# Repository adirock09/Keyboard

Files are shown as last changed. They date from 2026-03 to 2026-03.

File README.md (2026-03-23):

# Keyboard
I wanted to make a mecanical keyboard ,So i Choose a 60% layout Keyboard as it is compact and funtional enough. We will be using switch matrix wo we need less gpio pins
## Features

- Base on Raspberry pico
- Has 61 keys ( 60% Keyboard Matrix)

- ## 🧾 Bill of Materials (BOM)

| # | Item | Description | Quantity | Unit Price (USD) | Total (USD) | Link |
|---|---|---|---|---|---|---|
| 1 | 80Retros x HMX Volume | Mechanical switches (pack of 35) | 2 packs | 17.8 | 35.6 | https://stackskb.com/store/hmx-volume-0-pack-of-35/ |
| 2 | 1N4148 Diode | DO-35 switching diode | 61 | 0 | 0 | | Already have
| 3 | Raspberry Pi Pico H | RP2040 microcontroller board | 1 | 5.5 | 5.5 | https://robu.in/product/raspberry-pi-pico-with-headers/ |
| 4 | MAO Keycap Set | Full keycap set | 1 | 44.5 | 44.5 | https://stackskb.com/store/akko-panda-mao-keycap-set-142-key/ |
| 5 | Screw-In Stabilizers V2 | Keyboard stabilizers | 1 set | 17.1 | 17.1 | https://stackskb.com/store/durock-smokey-screw-in-stabilizers-v2/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 |
| 6 | PCB + Shipping | PCB fabrication (JLCPCB) | 1 | 29.51 | 29.51 | https://jlcpcb.com |

### 💰 Total Cost
**$132.21 USD**<br>
I am bidding for **100 USD** and rest **money will be paid by me myself**.

## Hardware
- Raspberry Pico 
- Cherry MX compatible Switches
- Diode
- 2 layer PCB

## Firmware
- It is Based on KMK and Circuit Python

- ### Schematic
Screenshot (171)

- ###  PCB Design
Screenshot (170)

- ### 3D Design
- <br>
Screenshot (284)

<br>
Screenshot (281)

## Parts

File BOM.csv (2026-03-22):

Index | Quantity | Part Number | Manufacturer Part Number | Description | Available | Unit Price | Extended Price USD | Link
1 | 2 (pack of 35) | 1644-MX2A-HC1B-ND | 80Retros x HMX Volume |  | 2 | 17.8 | 35.6 | https://stackskb.com/store/hmx-volume-0-pack-of-35/
2 | 61 | 1N4148FSCT-ND | 1N4148TR | DIODE STANDARD 100V 200MA DO35 | Already have | 0 | 0
3 | 1 | 2648-SC0917-ND | SC0917 | Raspberry Pi Pico H RP2040 | 1 | 5.5 | 5.5 | https://robu.in/product/raspberry-pi-pico-with-headers/
4 | 1 | Keycaps Set |  | MAO Keycap Set |  | 44.5 | 44.5 | https://stackskb.com/store/akko-panda-mao-keycap-set-142-key/
5 | 1 | Stabilizer |  | Screw-In Stabilizers V2 |  | 17.1 | 17.1 | https://stackskb.com/store/durock-smokey-screw-in-stabilizers-v2/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
6 | 1 | PCB + Shipping | JLCPCB | PCB fabrication and shipping |  | 29.51 | 29.51 | https://jlcpcb.com

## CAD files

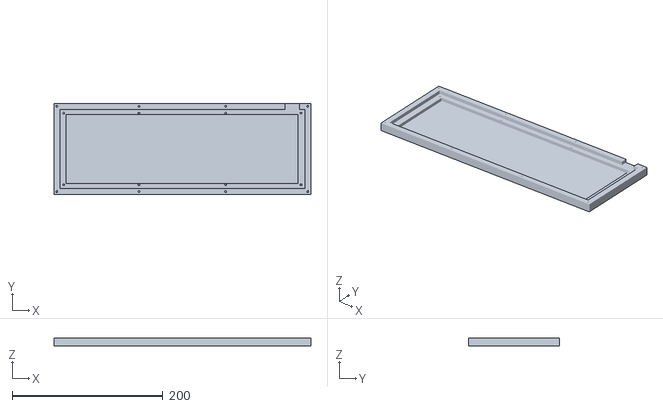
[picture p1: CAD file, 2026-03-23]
KeyBoard/Production/LowCover.stl
341.0 x 121.0 x 11.2

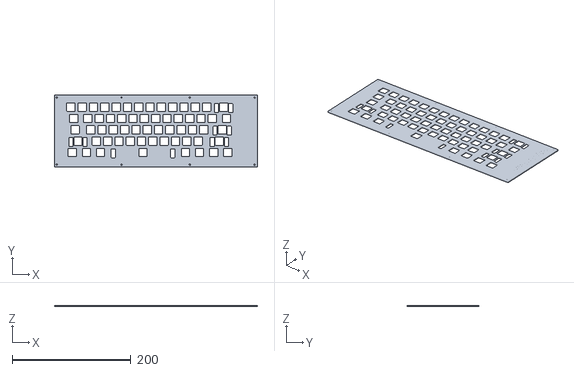
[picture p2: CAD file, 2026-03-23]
KeyBoard/Production/UpCase.stl
341.8 x 121.2 x 2.00

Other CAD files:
KeyBoard/CAD/Keyboard(2).f3d

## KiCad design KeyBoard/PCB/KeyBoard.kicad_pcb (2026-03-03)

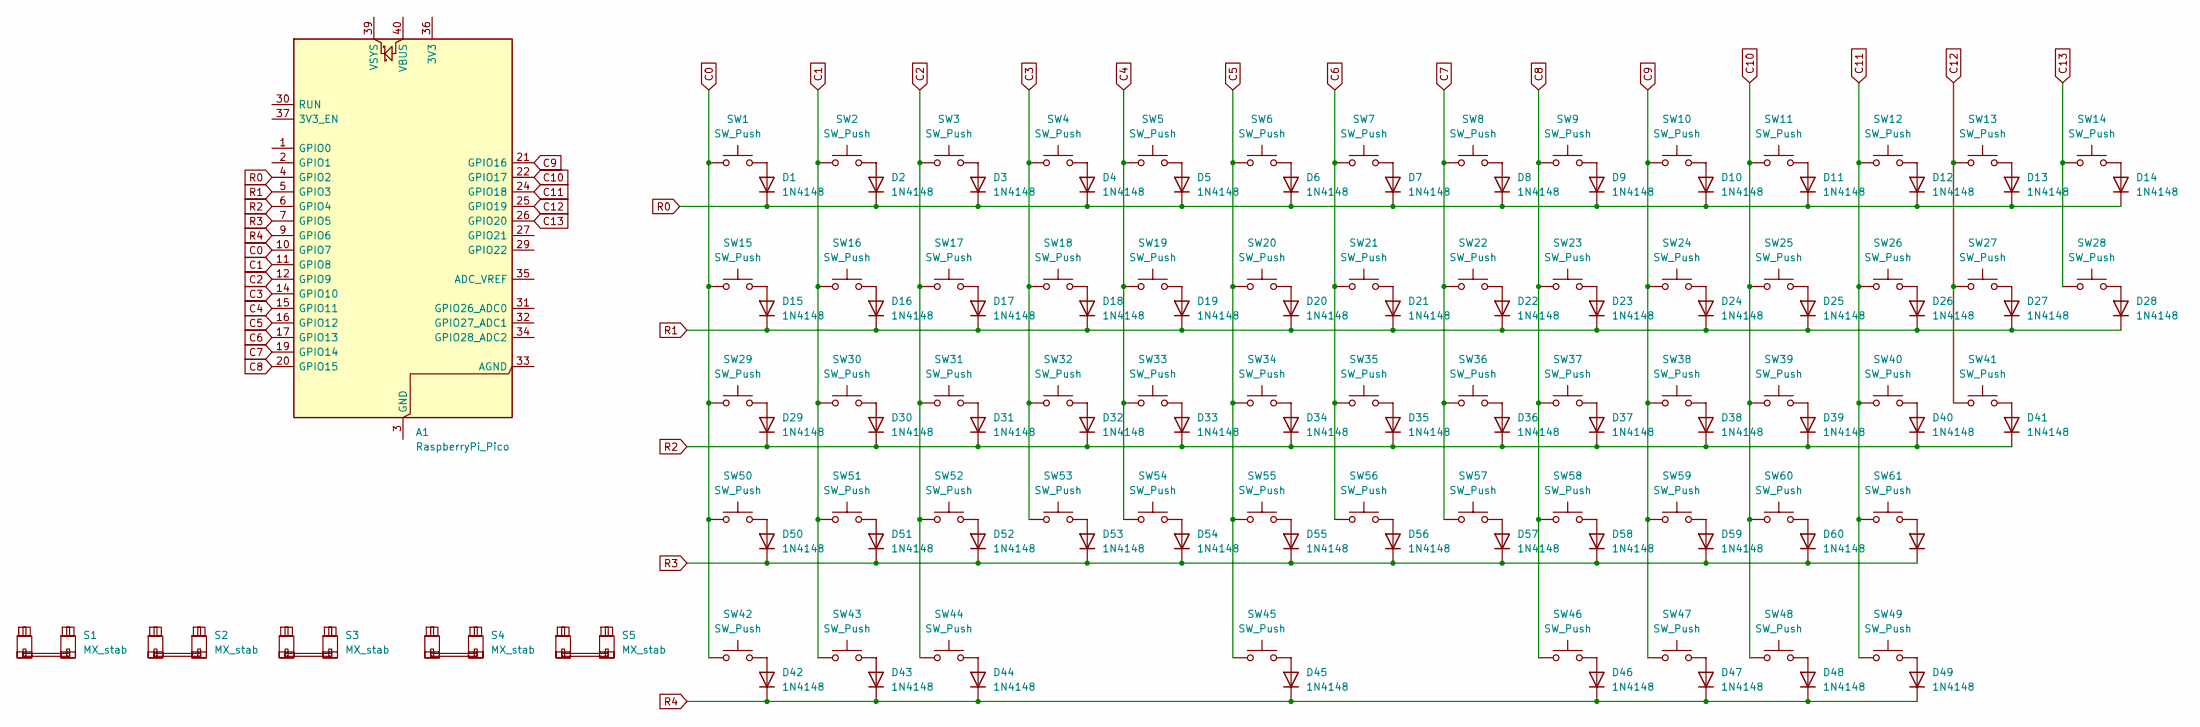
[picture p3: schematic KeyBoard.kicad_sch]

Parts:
A1: RaspberryPi_Pico; RaspberryPi_Pico_Common_Unspecified
D1, D2, D3, D4, D5, D6, D7, D8, D9, D10, D11, D12, D13, D14, D15, D16, D17, D18, D19, D20, D21, D22, D23, D24, D25, D26, D27, D28, D29, D30, D31, D32, D33, D34, D35, D36, D37, D38, D39, D40, D41, D42, D43, D44, D45, D46, D47, D48, D49, D50, D51, D52, D53, D54, D55, D56, D57, D58, D59, D60, D61: 1N4148; D_DO-35_SOD27_P7.62mm_Horizontal
S1: MX_stab; STAB_MX_2u
S2, S3: MX_stab; STAB_MX_2.25u
S4: MX_stab; STAB_MX_2.75u
S5: MX_stab; STAB_MX_6.25u
SW1, SW2, SW3, SW4, SW5, SW6, SW7, SW8, SW9, SW10, SW11, SW12, SW13, SW16, SW17, SW18, SW19, SW20, SW21, SW22, SW23, SW24, SW25, SW26, SW27, SW30, SW31, SW32, SW33, SW34, SW35, SW36, SW37, SW38, SW39, SW40, SW51, SW52, SW53, SW54, SW55, SW56, SW57, SW58, SW59, SW60: SW_Push; SW_Cherry_MX_1.00u_PCB
SW14: SW_Push; SW_Cherry_MX_2.00u_PCB
SW15: SW_Push; SW_Cherry_MX_1.50u_PCB
SW28: SW_Push; SW_Cherry_MX_1.50u_Plate
SW29: SW_Push; SW_Cherry_MX_1.75u_PCB
SW41, SW50: SW_Push; SW_Cherry_MX_2.25u_PCB
SW42, SW43, SW44, SW46, SW48, SW49: SW_Push; SW_Cherry_MX_1.25u_PCB
SW45: SW_Push; SW_Cherry_MX_6.25u_PCB
SW47: SW_Push; SW_Cherry_MX_1.25u_Plate
SW61: SW_Push; SW_Cherry_MX_2.75u_PCB

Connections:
C0: A1.10 (GPIO7), SW1.1, SW15.1, SW29.1, SW42.1, SW50.1
C1: A1.11 (GPIO8), SW2.1, SW16.1, SW30.1, SW43.1, SW51.1
C2: A1.12 (GPIO9), SW3.1, SW17.1, SW31.1, SW44.1, SW52.1
C3: A1.14 (GPIO10), SW4.1, SW18.1, SW32.1, SW53.1
C4: A1.15 (GPIO11), SW5.1, SW19.1, SW33.1, SW54.1
C5: A1.16 (GPIO12), SW6.1, SW20.1, SW34.1, SW45.1, SW55.1
C6: A1.17 (GPIO13), SW7.1, SW21.1, SW35.1, SW56.1
C7: A1.19 (GPIO14), SW8.1, SW22.1, SW36.1, SW57.1
C8: A1.20 (GPIO15), SW9.1, SW23.1, SW37.1, SW46.1, SW58.1
C9: A1.21 (GPIO16), SW10.1, SW24.1, SW38.1, SW47.1, SW59.1
C10: A1.22 (GPIO17), SW11.1, SW25.1, SW39.1, SW48.1, SW60.1
C11: A1.24 (GPIO18), SW12.1, SW26.1, SW40.1, SW49.1, SW61.1
C12: A1.25 (GPIO19), SW13.1, SW27.1, SW41.1
C13: A1.26 (GPIO20), SW14.1, SW28.1
unnamed: A1.3 (GND), A1.8 (GND), A1.13 (GND), A1.18 (GND), A1.23 (GND), A1.28 (GND), A1.38 (GND)
unnamed: D1.2 (A), SW1.2
unnamed: D2.2 (A), SW2.2
unnamed: D3.2 (A), SW3.2
unnamed: D4.2 (A), SW4.2
unnamed: D5.2 (A), SW5.2
unnamed: D6.2 (A), SW6.2
unnamed: D7.2 (A), SW7.2
unnamed: D8.2 (A), SW8.2
unnamed: D9.2 (A), SW9.2
unnamed: D10.2 (A), SW10.2
unnamed: D11.2 (A), SW11.2
unnamed: D12.2 (A), SW12.2
unnamed: D13.2 (A), SW13.2
unnamed: D14.2 (A), SW14.2
unnamed: D15.2 (A), SW15.2
unnamed: D16.2 (A), SW16.2
unnamed: D17.2 (A), SW17.2
unnamed: D18.2 (A), SW18.2
unnamed: D19.2 (A), SW19.2
unnamed: D20.2 (A), SW20.2
unnamed: D21.2 (A), SW21.2
unnamed: D22.2 (A), SW22.2
unnamed: D23.2 (A), SW23.2
unnamed: D24.2 (A), SW24.2
unnamed: D25.2 (A), SW25.2
unnamed: D26.2 (A), SW26.2
unnamed: D27.2 (A), SW27.2
unnamed: D28.2 (A), SW28.2
unnamed: D29.2 (A), SW29.2
unnamed: D30.2 (A), SW30.2
unnamed: D31.2 (A), SW31.2
unnamed: D32.2 (A), SW32.2
unnamed: D33.2 (A), SW33.2
unnamed: D34.2 (A), SW34.2
unnamed: D35.2 (A), SW35.2
unnamed: D36.2 (A), SW36.2
unnamed: D37.2 (A), SW37.2
unnamed: D38.2 (A), SW38.2
unnamed: D39.2 (A), SW39.2
unnamed: D40.2 (A), SW40.2
unnamed: D41.2 (A), SW41.2
unnamed: D42.2 (A), SW42.2
unnamed: D43.2 (A), SW43.2
unnamed: D44.2 (A), SW44.2
unnamed: D45.2 (A), SW45.2
unnamed: D46.2 (A), SW46.2
unnamed: D47.2 (A), SW47.2
unnamed: D48.2 (A), SW48.2
unnamed: D49.2 (A), SW49.2
unnamed: D50.2 (A), SW50.2
unnamed: D51.2 (A), SW51.2
unnamed: D52.2 (A), SW52.2
unnamed: D53.2 (A), SW53.2
unnamed: D54.2 (A), SW54.2
unnamed: D55.2 (A), SW55.2
unnamed: D56.2 (A), SW56.2
unnamed: D57.2 (A), SW57.2
unnamed: D58.2 (A), SW58.2
unnamed: D59.2 (A), SW59.2
unnamed: D60.2 (A), SW60.2
unnamed: D61.2 (A), SW61.2
R0: A1.4 (GPIO2), D1.1 (K), D2.1 (K), D3.1 (K), D4.1 (K), D5.1 (K), D6.1 (K), D7.1 (K), D8.1 (K), D9.1 (K), D10.1 (K), D11.1 (K), D12.1 (K), D13.1 (K), D14.1 (K)
R1: A1.5 (GPIO3), D15.1 (K), D16.1 (K), D17.1 (K), D18.1 (K), D19.1 (K), D20.1 (K), D21.1 (K), D22.1 (K), D23.1 (K), D24.1 (K), D25.1 (K), D26.1 (K), D27.1 (K), D28.1 (K)
R2: A1.6 (GPIO4), D29.1 (K), D30.1 (K), D31.1 (K), D32.1 (K), D33.1 (K), D34.1 (K), D35.1 (K), D36.1 (K), D37.1 (K), D38.1 (K), D39.1 (K), D40.1 (K), D41.1 (K)
R3: A1.7 (GPIO5), D50.1 (K), D51.1 (K), D52.1 (K), D53.1 (K), D54.1 (K), D55.1 (K), D56.1 (K), D57.1 (K), D58.1 (K), D59.1 (K), D60.1 (K), D61.1 (K)
R4: A1.9 (GPIO6), D42.1 (K), D43.1 (K), D44.1 (K), D45.1 (K), D46.1 (K), D47.1 (K), D48.1 (K), D49.1 (K)

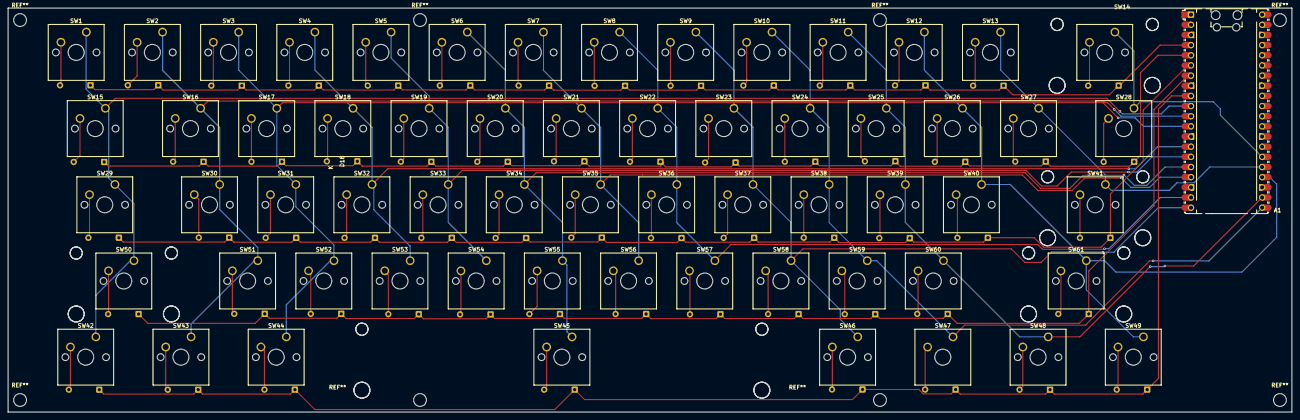
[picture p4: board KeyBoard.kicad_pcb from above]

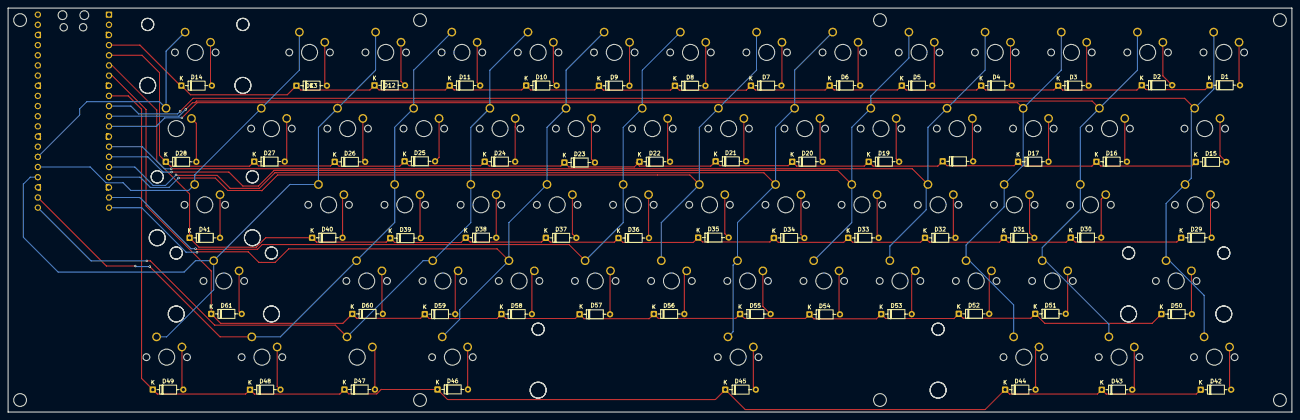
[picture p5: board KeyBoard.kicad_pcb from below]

Board: 2 copper layers, 321.0 x 101.0 mm, 128 parts (61 on the bottom side), 81 nets.

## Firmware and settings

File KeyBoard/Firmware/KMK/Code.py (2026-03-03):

import board
from kmk.kmk_keyboard import KMKKeyboard
from kmk.keys import KC
from kmk.scanners import DiodeOrientation
from kmk.modules.layers import Layers

keyboard = KMKKeyboard()
keyboard.modules.append(Layers())

# ===== MATRIX PINS (MATCH YOUR SCHEMATIC) =====
keyboard.row_pins = (
    board.GP26,
    board.GP27,
    board.GP28,
    board.GP29,
    board.GP6,
)

keyboard.col_pins = (
    board.GP0,
    board.GP1,
    board.GP2,
    board.GP3,
    board.GP4,
    board.GP5,
    board.GP7,
    board.GP8,
    board.GP9,
    board.GP10,
    board.GP11,
    board.GP12,
    board.GP13,
    board.GP14,
)

keyboard.diode_orientation = DiodeOrientation.COLUMNS

# ===== KEYMAP =====
keyboard.keymap = [
    [
        KC.ESC, KC.N1, KC.N2, KC.N3, KC.N4, KC.N5, KC.N6, KC.N7, KC.N8, KC.N9, KC.N0, KC.MINS, KC.EQL, KC.BSPC,
        KC.TAB, KC.Q,  KC.W,  KC.E,  KC.R,  KC.T,  KC.Y,  KC.U,  KC.I,  KC.O,  KC.P,  KC.LBRC, KC.RBRC, KC.BSLS,
        KC.CAPS,KC.A,  KC.S,  KC.D,  KC.F,  KC.G,  KC.H,  KC.J,  KC.K,  KC.L,  KC.SCLN, KC.QUOT, KC.ENT,
        KC.LSFT,KC.Z,  KC.X,  KC.C,  KC.V,  KC.B,  KC.N,  KC.M,  KC.COMM,KC.DOT, KC.SLSH, KC.RSFT,
        KC.LCTL,KC.LGUI,KC.LALT,KC.SPC,KC.RALT,KC.RGUI,KC.MO(1),KC.RCTL
    ],
    [
        KC.GRV, KC.F1, KC.F2, KC.F3, KC.F4, KC.F5, KC.F6, KC.F7, KC.F8, KC.F9, KC.F10, KC.F11, KC.F12, KC.DEL,
        KC.NO,  KC.NO, KC.UP, KC.NO, KC.NO, KC.NO, KC.NO, KC.NO, KC.NO, KC.NO, KC.NO, KC.NO, KC.NO, KC.NO,
        KC.NO, KC.LEFT,KC.DOWN,KC.RIGHT,KC.NO,KC.NO,KC.NO,KC.NO,KC.NO,KC.NO,KC.NO,KC.NO,KC.NO,
        KC.NO, KC.NO, KC.NO, KC.NO, KC.NO, KC.NO, KC.NO, KC.NO, KC.NO, KC.NO, KC.NO, KC.NO,
        KC.NO, KC.NO, KC.NO, KC.NO, KC.NO, KC.NO, KC.NO, KC.NO
    ]
]

if __name__ == '__main__':
    keyboard.go()
